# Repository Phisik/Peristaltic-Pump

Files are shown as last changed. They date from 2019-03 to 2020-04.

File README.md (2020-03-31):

# SUMMARY
There are several peristaltic pump projects on Thingiverse. However most of them lack source codes and could not be adjusted to use with different hose and bearings. I designed fully parametric peristaltic pump. It can be customized to use any silicon hose, any Nema motor, and any bearings. Source files are supplied. Feel free to modify it and adapt to suit your needs.

I have used silicon hose with OD=7 mm, ID=5.5 mm, and 0.75 mm wall. With that hose Nema 17HS4401S motor was able to pump 700 ml per minute (42 litres per hour) easily. Hoses with thicker walls may require to reduce motor speed or motor with higher torque.

# 3D PRINTING
The latest STL and SCAD source files of pump head are available at https://www.thingiverse.com/thing:3148717. I used 50% infill and 3 perimeters. The higher infill percentage the better. If rotor movement is too tight hose_clearance parameter can be increased. I use PET-G plastic for the case, and ABS for pump head to be able to pump hot liquids.

# HARDWARE
Additionally to pump head you will need to get some electronics:

    1. Nema stepper motor, e.g 17HS4401S. ~$8 
       https://www.aliexpress.com/item/32376023464.html
    2. Stepper motor driver, e.g A4988. ~$1  
       https://www.aliexpress.com/item/1817501276.html
    3. Arduino board. I used Arduino pro mini. ~ $2 
       https://www.aliexpress.com/item/32293707392.html
    4. Rotary encoder with button + 2 resistors or KY-040 Encoder Module. ~ $1 
       https://www.aliexpress.com/item/32474584136.html
    5. 1602 LCD with I2C converter. ~ $2 
       https://www.aliexpress.com/item/32836972320.html
    6. Bearings. I used 6 pcs of 605zz bearings. ~$10 for 50 pcs 
       https://www.aliexpress.com/item/32245721720.html
    7. Power supply 12V 1-2A. ~$4 
       https://www.aliexpress.com/item/1000001113368.html
    8. Rubber legs ~$1.5 for 20pcs 
       https://www.aliexpress.com/item/32844587782.html
    9. DC-DC converter ~$1.5 
       https://www.aliexpress.com/item/32261885063.html
    10. 2 springs ~$0.1  
        https://aliexpress.ru/item/2053018943.html
    11. Wires, screws, nuts etc.

I have ordered all parts from AliExpress. Links are provided as an example, you may not need 50pcs of bearings and can order only 10pcs. Total cost of the pump was about $35 including plastic for printing & other elecronic components.

# SOFTWARE
Source codes of Arduino firmware for DIY Nema motor based peristaltic pump are available in preset repository. 

Main features:

    1. Adjustable speed via RPM
    2. Adjustable speed via flow in ml per min
    3. Pumping predefined amount of liquid
    4. Pump calibration
    5. Soft start/stop
	6. Moisture sensor support to detect hose failure
	7. External control via analog/PWM signal
	8. Motor uptime & total pumped volume calculation 

Modes can be switched by single click. Double click is used for start/stop. Button hold enables pump calibration mode.

Video showing the pump in action: https://youtu.be/RnriTiulfPw

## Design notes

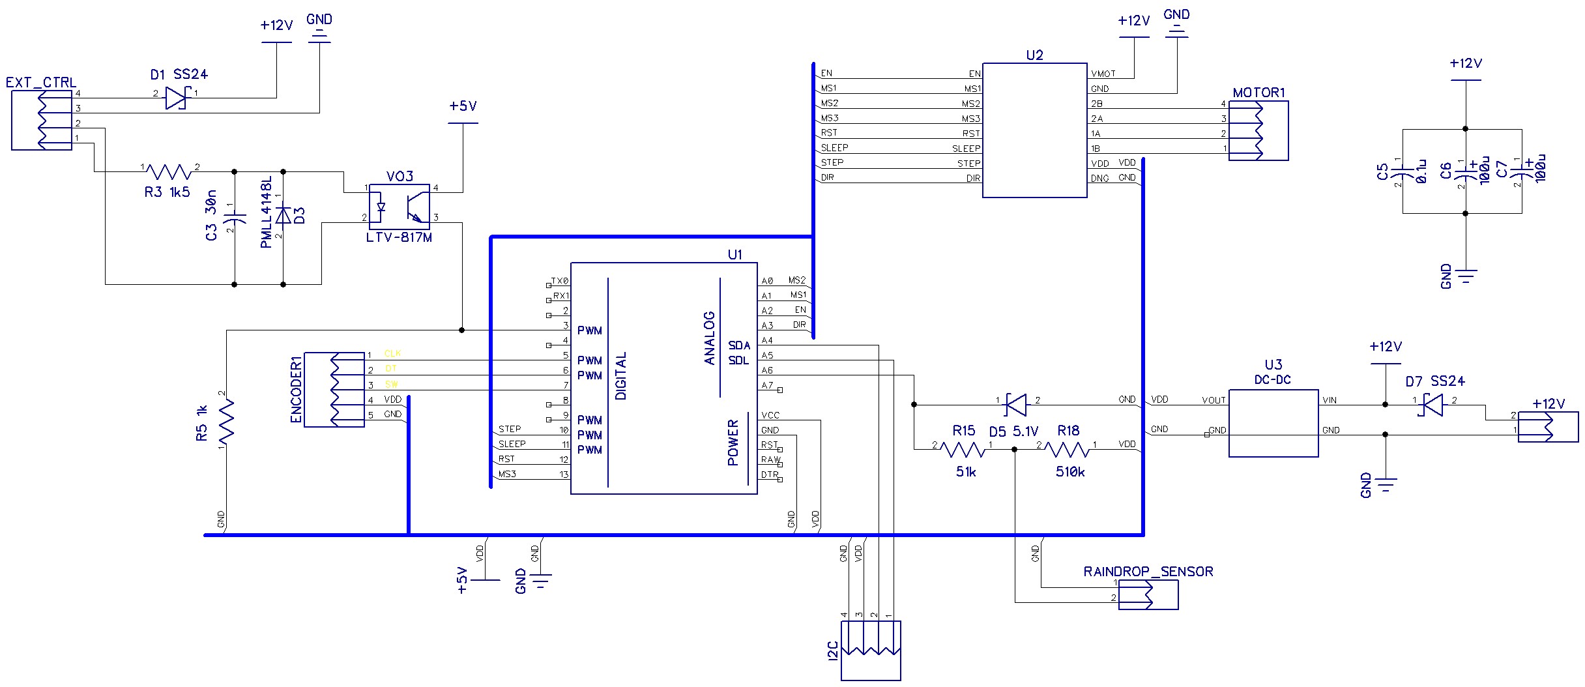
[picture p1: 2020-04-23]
docs/schematics.jpg

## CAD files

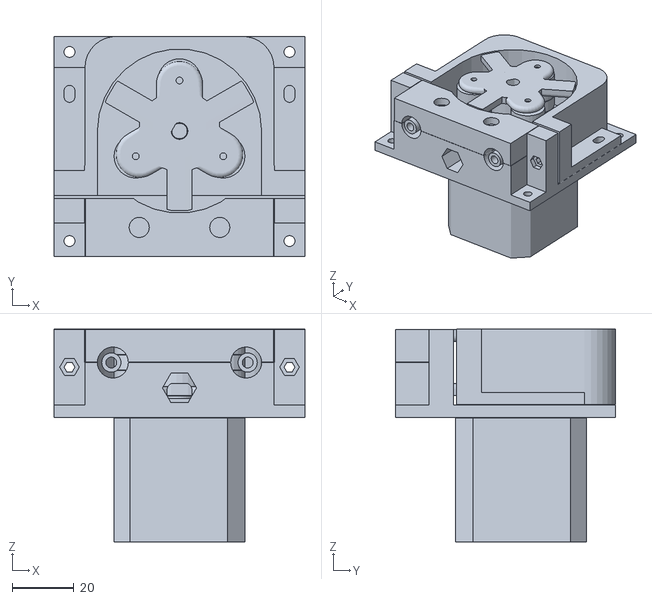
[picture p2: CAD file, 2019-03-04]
scad/head-assembly.stl
81.0 x 71.0 x 68.7

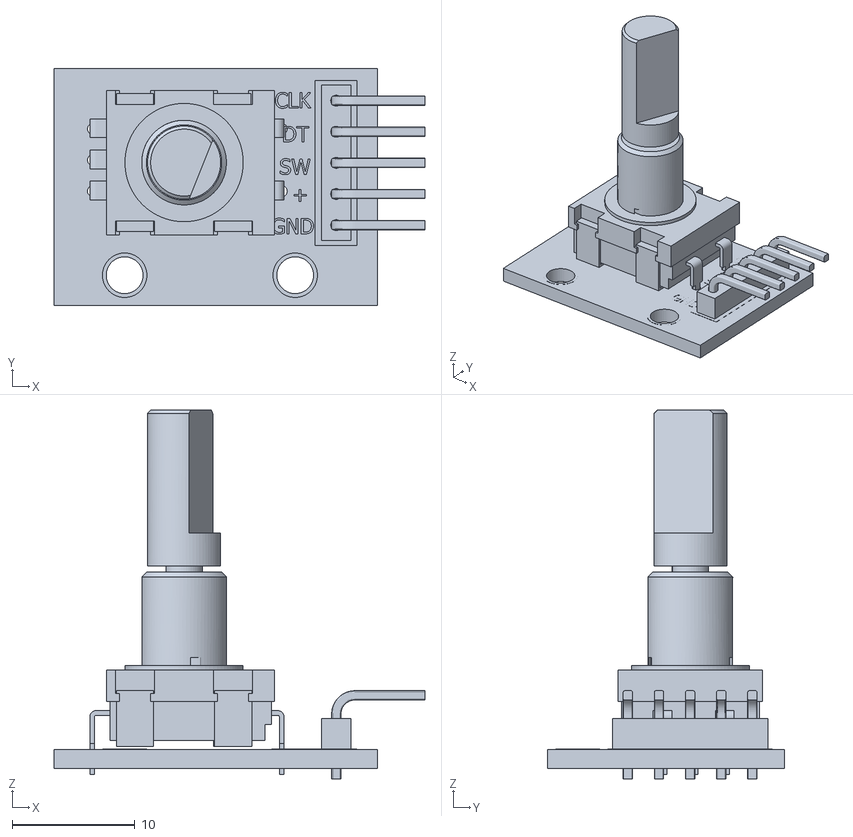
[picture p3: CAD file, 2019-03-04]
deps/ky-040.stl
30.3 x 19.3 x 30.1

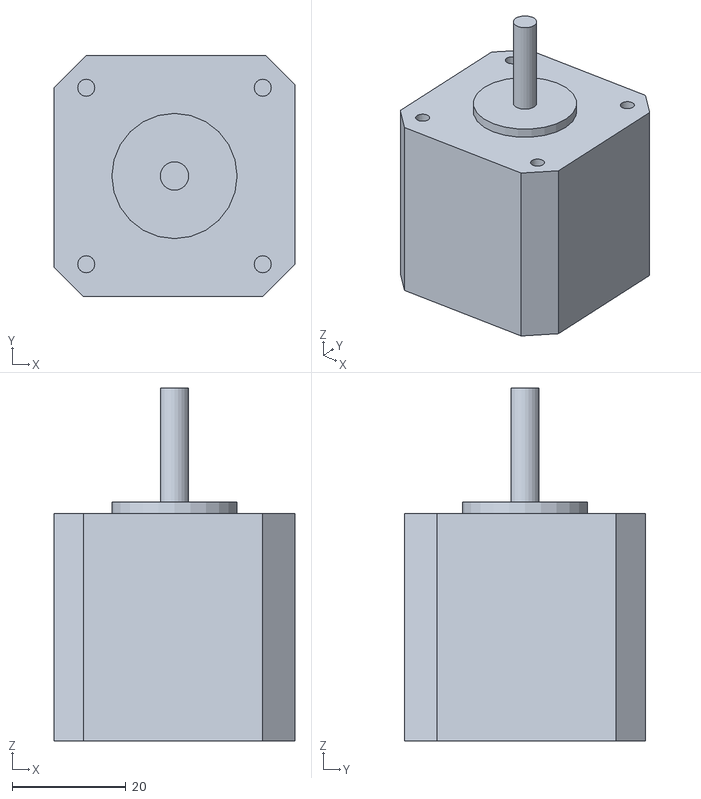
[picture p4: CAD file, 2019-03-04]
scad/deps/Nema17_40h.stl
42.3 x 42.3 x 62.0

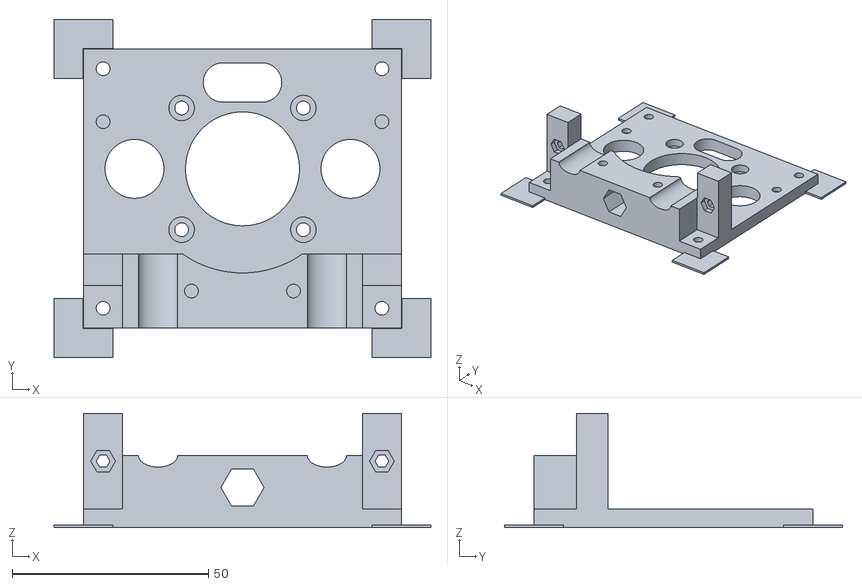
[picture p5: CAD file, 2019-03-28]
stl/pump-stator-base-with-support.stl
96.0 x 86.0 x 29.1

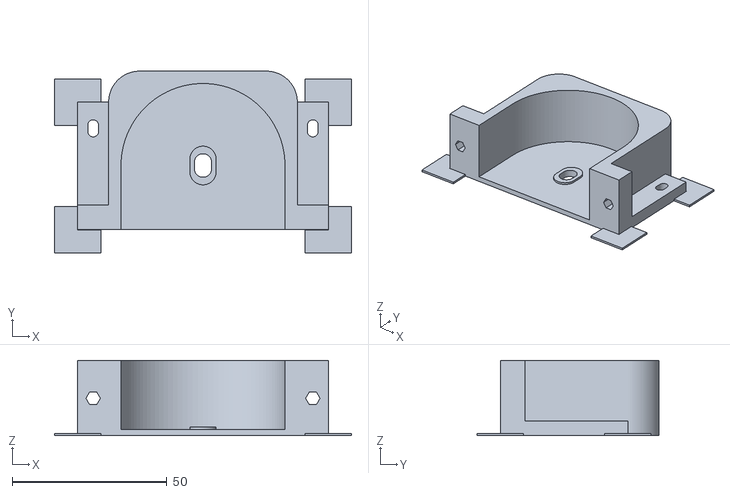
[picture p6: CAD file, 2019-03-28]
stl/pump-stator-support-with-support.stl
96.0 x 58.7 x 24.4

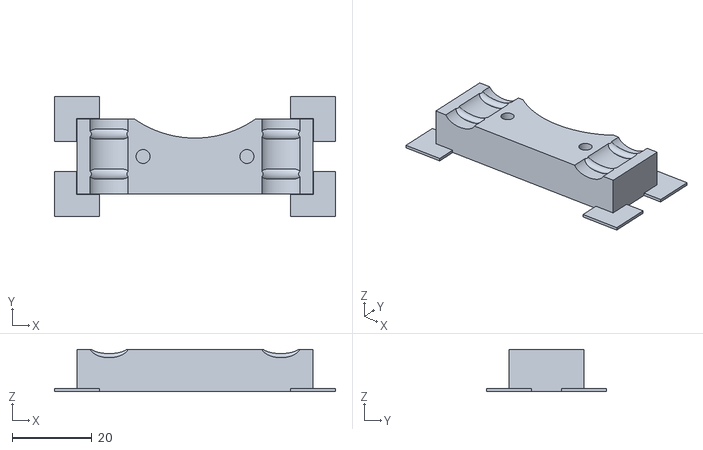
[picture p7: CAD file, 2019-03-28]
stl/pump-stator-cover-with-support.stl
70.3 x 30.0 x 10.6

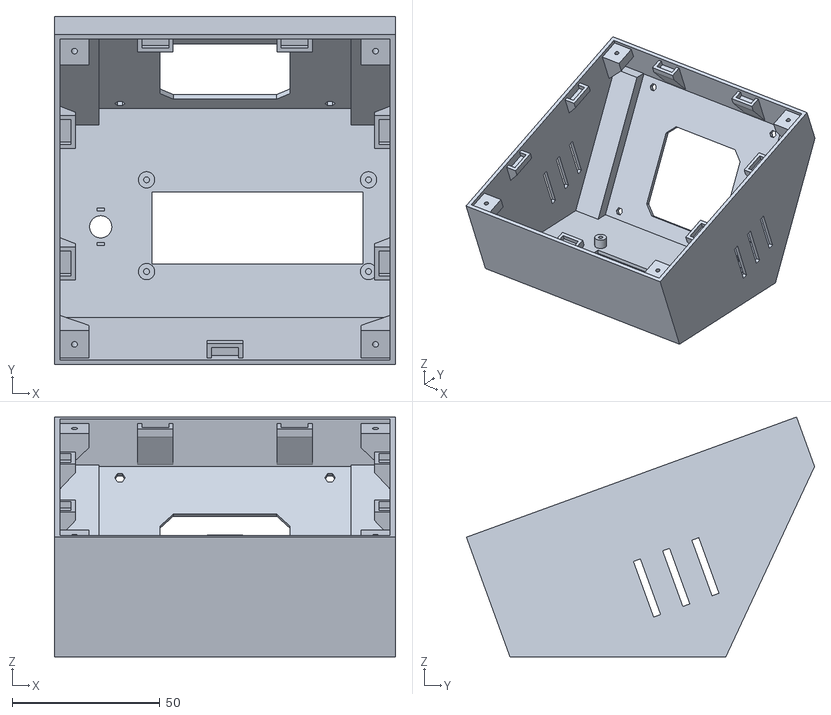
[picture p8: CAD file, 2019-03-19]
stl/case.stl
115.2 x 117.7 x 81.1

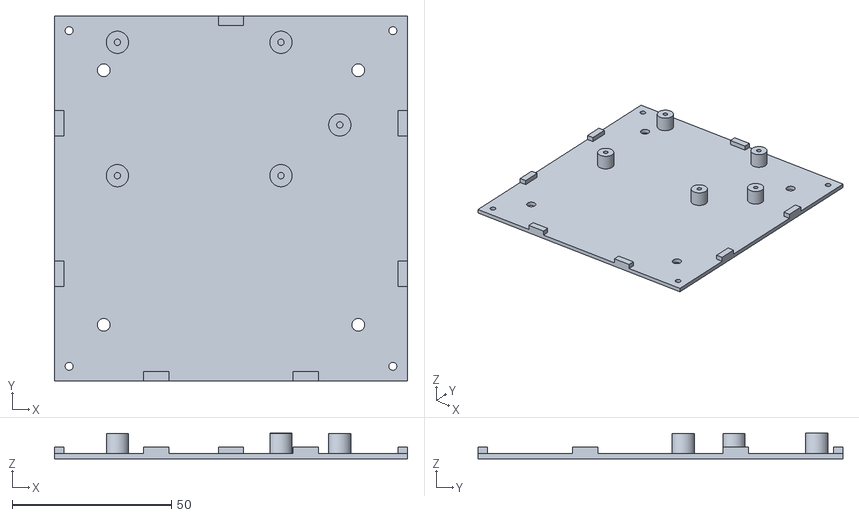
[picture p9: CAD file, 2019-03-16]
stl/case-bottom.stl
110.9 x 114.7 x 8.05

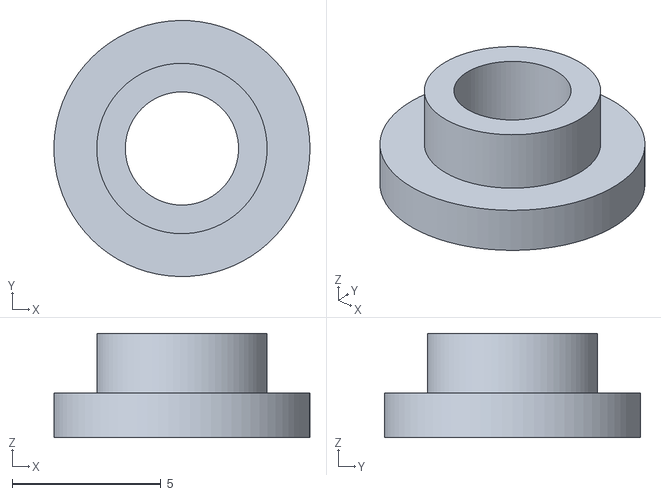
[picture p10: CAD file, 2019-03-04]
stl/spring-guide.stl
8.60 x 8.60 x 3.50

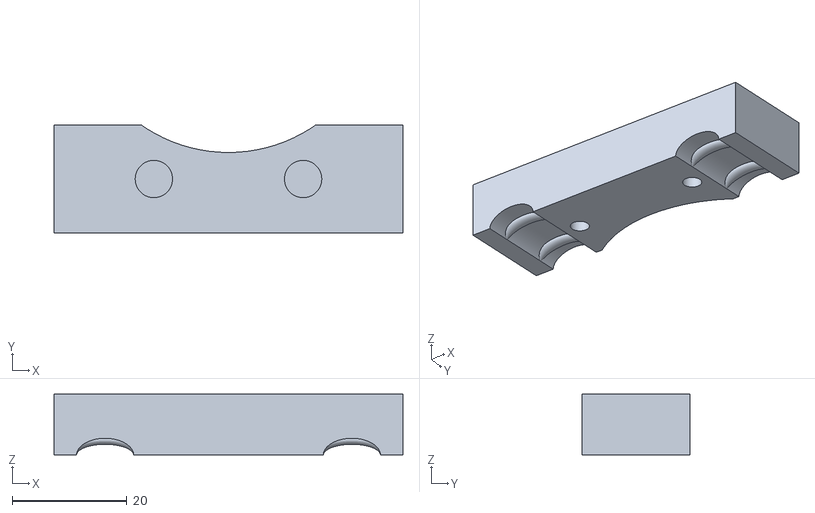
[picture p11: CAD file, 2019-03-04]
stl/pump-stator-cover.stl
60.8 x 18.8 x 10.6

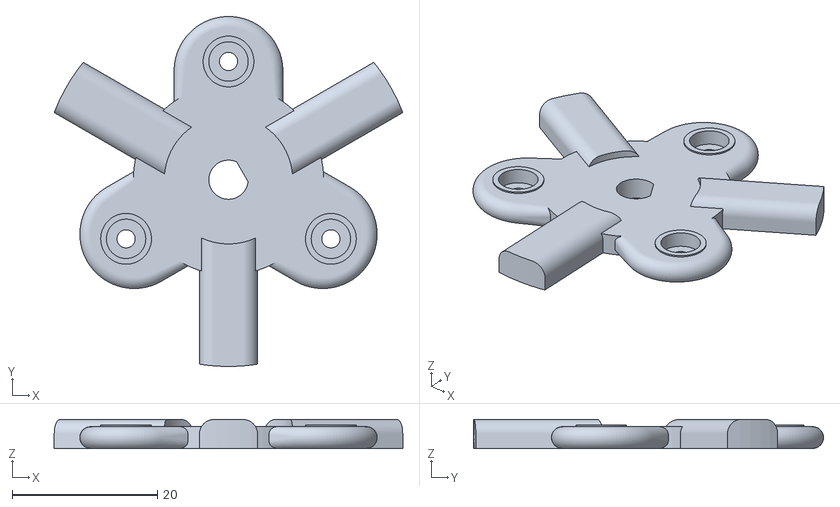
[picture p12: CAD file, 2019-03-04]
stl/pump-rotor-cover.stl
48.0 x 48.2 x 4.00

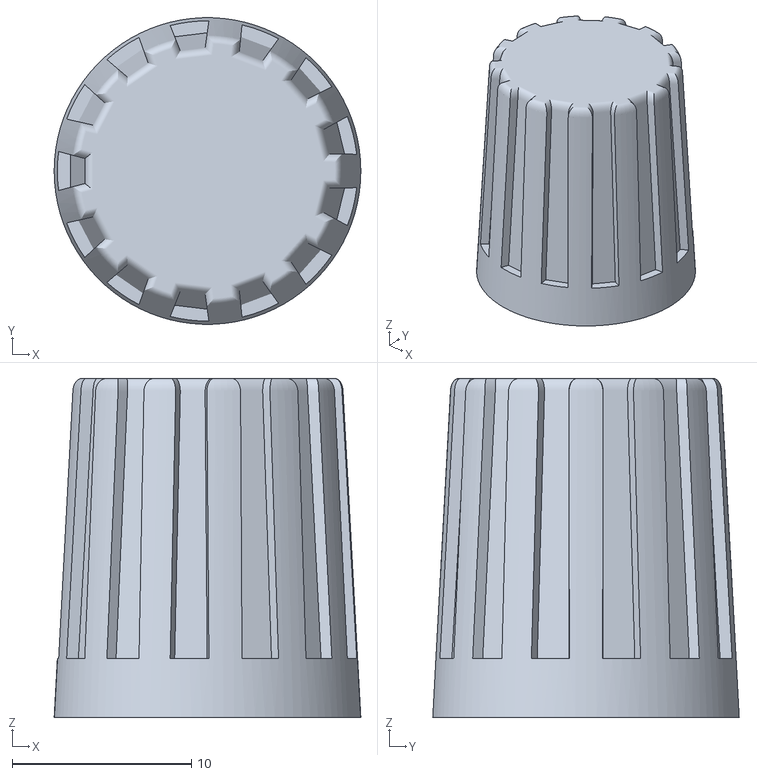
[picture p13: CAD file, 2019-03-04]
stl/encoder-knob.stl
17.1 x 17.1 x 18.9

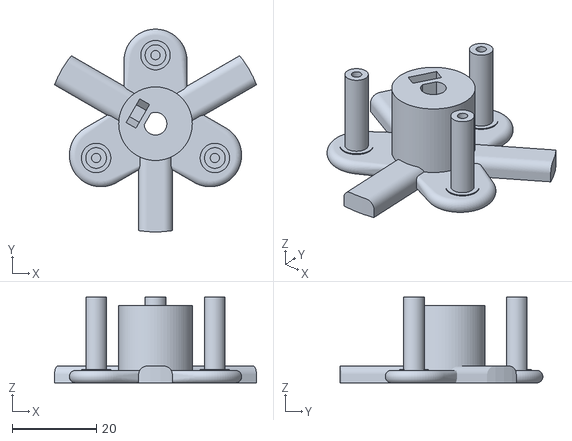
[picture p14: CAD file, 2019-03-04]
stl/pump-rotor-base.stl
48.0 x 48.2 x 20.4

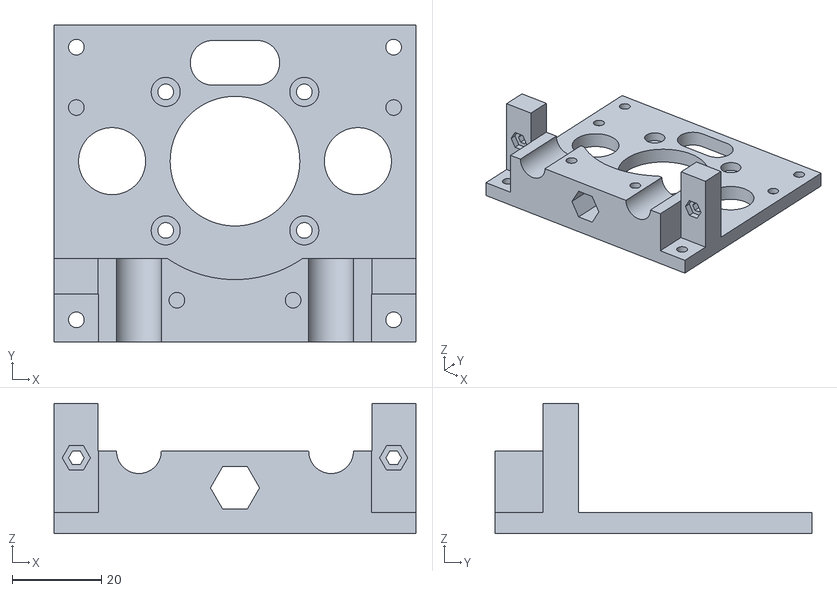
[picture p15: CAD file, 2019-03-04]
stl/pump-stator-base.stl
81.0 x 71.0 x 29.1

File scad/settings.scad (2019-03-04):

// Created by Phisik on 2018-12-16
// Main settings header for peristaltic pump

// Licence GPL

// some extra gap for clean difference render in preview
eps = 0.1;

// Part smoothness, the more the better
$fn = 100;

layer_height = 0.25;

// Silicon hose settings
//====================================================================================

// NB! The larger the hose radius the higher torque is required
r_hose = 22;        // radius of hose center line
                    // Update: after addition of groove hose center is at r_hose + hose_groove
d_hose = 9;         // hose external diameter

hose_wall = 1.5;   // hose wall thickness
					// NB! hose_wall affects both stator & rotor geometry
					
hose_clearance = 0.2;   // extra clearance between hose & bearings
						// NB! hose_clearance affects only rotor geometry
						// If you experience lack of suction reduce hose_clearance 
						// If motor misses steps increase hose_clearance, take motor with higher 
						// torque or hose with thinner wall

hose_fitting_delta_d = 1; // difference between hose and hose fitting diameter
						
						
// Stator settings
//====================================================================================
wall = 4;             // wall thickness, should be larger than hose_groove by 1mm or more
hose_groove = 0;     // NB! Rudiment form v1. Do not change. 
					 // groove depth for hose to stay in place 

h_base = 4.75;             // height of stator base
h_support_base = 2;		// height of support base

stator_support_gap = 1;		// gap between support & stator base for spring tension

stator_facet = 10;   // facets of outer support corners

mount_width  = 8;
mount_length = 10;

d_screw = 3.5;           // screw diameter
d_nut = 6.5;             // nut & screw head diameter
d_nut_tight = 5.5/0.87; // nut diameter for nuts to be fitted with soldering iron

l_handle = 10;

r_water_sink = 5.5;

need_nut_cuts_in_support = 0; // cut holes for nuts in support
need_nut_cuts_in_stator  = 1; // cut holes for support nut in stator

hose_fixator_length = 15;  // length of hose inset for fixing it on the stator


// Bearing settings
//====================================================================================
bearingNum = 3;     // Number of bearings per arm

h_bearing = 5;      // bearing height
d_bearing = 14;     // OD
d_bearing_axis = 5;         // ID
w_axis = 1;         // thickness of inner bushing



// Rotor settings
//==================================================================================== 
d_rotor = 17.5;   // Outer rotor diameter

arm_num = 3;    // number of rotor arms
w_arm  = 15;    // arm width
h_arm = 3;      // arm height

enable_hose_guides = 1;
w_hose_guide = 8;
hose_guide_clearance = 0.75;
r_hose_guide_facet = 2;

gap = 0.2;      // some clearance between joins & moving parts

arm_clearance = 4;  // clearance between arm and stator

bearing_axes_clearance = 0.075;  	     // clearance on rotor base between bearings and axes
rotor_bearing_axes_clearance = 0.45;  // clearance on rotor cap between axes and holes
bearing_clearance = 1; 				 // distance from stator base to the lowest arms

// 1602 lcd settings
//====================================================================================
y_lcd_hole = 31;
x_lcd_hole = 75;
d_lcd_hole = 3;

l_lcd_plate = 80;
w_lcd_plate = 36.11;
h_lcd_plate = 1.6;

l_lcd = 71.5;
w_lcd = 24.5;
h_lcd = 8.75;

x_lcd_shift = -0.1;
y_lcd_shift = +0.75;

l_lcd_i2c = 42;
w_lcd_i2c = 19;
h_lcd_i2c = 1.5;


// Nema 17 settings
//====================================================================================
nema_screw_distance = 31;  
nema_shaft_diameter = 5.5;
nema_shaft_height = 25;
nema_knob_diameter = 23;
nema_knob_height = 2.5;
nema_width = 42.3;
nema_angle_cut = 4;

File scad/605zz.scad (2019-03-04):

module 605zz() {
	difference(){
		cylinder(d=14, h=5);
		cylinder(d=11, h=5);
	}
	difference(){
		cylinder(d=7, h=5);
		cylinder(d=5, h=5);
	}

	translate([0,0,0.25])
	difference(){
		cylinder(d=11, h=4.5);
		cylinder(d=7, h=4.5);
	}
}

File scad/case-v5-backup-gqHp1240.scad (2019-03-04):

// Created by Phisik on 2018-10-20
// Case for open source peristaltic pump

// Licence GPL 
// You are free to distibute & contribute to this part in any form

// Settings
//==============================================================================
include <settings.v3>
use <lcd1602.scad>

assembly      = 0;   // render assembly
render_top    = 1;   // render top part
render_bottom = 0;   // render bottom part
render_side_panel = 1;   // render bottom part

enable_angle_support = 1;

h_layer_height = 0.25;
w_angle_support = 15;
n_support_layers = 3;
angle_support_clearance = 0.15;


rubber_legs = true;
d1_rubber_legs = 15;
d2_rubber_legs = 18;
h_rubber_legs  = 5;

h_case = 68;
w_case = 115;
l_case = 117;

nema_clearance = 0.8;

// Front panel settings
front_angle=20;
back_angle=45;
wall_case = 0.46*cos(front_angle)*4;
wall_size_scale = 1/cos(front_angle);  // when 3d printing tilded walls will be thicker




w_front_panel = w_lcd_plate + 36.8;

d_lcd_stand = d_lcd_hole+2.5;
d_lcd_stand_hole = 2;

r_ext = r_hose + d_hose/2 + wall - hose_groove;
handle_length = r_ext+l_handle;
w_back_panel = handle_length+r_ext;


extra_lcd_n_ecn_shift = 5;

lcd_clearance = -0.1;
x_1602_shift = 11;
y_1602_shift = -y_lcd_shift+extra_lcd_n_ecn_shift;
z_1602_shift = -6;

x_enc_shift = -40;
y_enc_shift = 2.2+extra_lcd_n_ecn_shift;
z_enc_shift = -8.5;


// PCB settings
l_pcb = 58.4;
h_pcb = 1.6;
w_pcb = 49;
x_pcb_hole = 51.4;
y_pcb_hole = 41.91;
d_pcb_hole = 2;
x_shift_pcb = 0;
y_shift_pcb = -29.5;
z_shift_pcb = 8;
d_pcb_leg = 7;
d_pcb_leg_hole = 2;

alpha = 1;

// ventillation holes settings
n_vent = 3;
h_vent = 20;
w_vent = 2.5;
dist_vent = 8;
vent_y_shift = 45;
vent_z_shift = 27;

// bottom plate settings
d_bottom_legs_holes = 4;
d_bottom_holes = 2.5;
d_bottom_legs = 20;
h_bottom_legs = 4;
legs_shift = w_case/2-d_bottom_legs/2-7.5;
cover_clearance = 0.3;

// some extra clips to hold side walls
clip_shift = 30;
l_clip = 8;
w_clip = 3;
h_clip = 2;
clip_wall = 2;
clip_clearance = 0.5;

// bottom plate holders
holders_size = 10;
d_holder_hole = 2;

// Assemble all parts
//==============================================================================
if(assembly) {
    alpha = 1;
    

    color("red", alpha) 
        translate([x_shift_pcb, y_shift_pcb, z_shift_pcb]) 
        pcb();
    
    color("green", alpha) 
        translate([0,-l_case, h_case-w_back_panel*sin(back_angle)]) 
        rotate([back_angle, 0, 0])  
        translate([0,handle_length, 0]) 
        import("pump-v3-assembly.stl");
    
    if(render_top)       case_main();
    if(render_bottom)    { 
        bottom_cover(); 
        if(rubber_legs) color("gray") draw_rubber_legs(); 
    }
} else {
    if(render_top) {
        translate([0, -w_front_panel/2, 0])
        rotate([180+front_angle, 0, 0]) 
            translate([0, -wall_case, -h_case+w_front_panel*sin(front_angle)])
            case_main();
        
        difference(){
            union() {
                for(sx=[1, -1]) for(sy=[1, -1])
                    translate([sx*(l_case-wall_case)/2, sy*w_front_panel/2, n_support_layers*h_layer_height/2])
                    cube([w_angle_support, w_angle_support, h_layer_height*n_support_layers], center=true);

            }
            
            translate([0,0,h_layer_height/2]) hull(){
                h = 50; d=angle_support_clearance;
                cube([l_case-wall_case+d/2, w_front_panel+d, h_layer_height], center=true);
                translate([0,-h*sin(front_angle)+h*sin(back_angle-front_angle),h-h_layer_height])
                    cube([l_case-wall_case+d/2, w_front_panel+d+h*sin(front_angle)+h*sin(back_angle-front_angle), h_layer_height], center=true);
            }
        }
        
        // enable_angle_support = 1;
        //h_angle_support = 0.5;
        // w_angle_support = 10;
    }
    if(render_bottom)    bottom_cover();
}
// Assemble


// Bottom cover
//==============================================================================
module bottom_cover() {
    difference() {
        translate([-w_case/2 + wall_case + cover_clearance,
                   -l_case + wall_case + cover_clearance, 0]) 
           cube([
                w_case-2*wall_case-2*cover_clearance, 
                l_case-wall_case-2*cover_clearance, 
                wall_case], center=false);
    
        if(rubber_legs) {
            translate([0,-l_case/2 + 0.5*wall_case + cover_clearance, -eps]) {
                translate(legs_shift*[1,1,0])    
                    cylinder(d=d_bottom_legs_holes, h=h_bottom_legs);
                translate(legs_shift*[1,-1,0])    
                    cylinder(d=d_bottom_legs_holes, h=h_bottom_legs);
                translate(legs_shift*[-1,1,0])    
                    cylinder(d=d_bottom_legs_holes, h=h_bottom_legs);
                translate(legs_shift*[-1,-1,0])    
                    cylinder(d=d_bottom_legs_holes, h=h_bottom_legs);
           }
        } else {  
            translate([x_shift_pcb, y_shift_pcb, 0]){
              translate([x_pcb_hole, y_pcb_hole, -eps]/2)
                    cylinder(d=d_bottom_holes, h=wall_case+1);
                translate([x_pcb_hole, -y_pcb_hole, -eps]/2)
                    cylinder(d=d_bottom_holes, h=wall_case+1);
                translate([-x_pcb_hole, y_pcb_hole, -eps]/2)
                    cylinder(d=d_bottom_holes, h=wall_case+1);
                translate([-x_pcb_hole, -y_pcb_hole, -eps]/2)
                    cylinder(d=d_bottom_holes, h=wall_case+1);
            } // pcb holes
        }
        
                 
        // holders for bottom plate
        translate([-w_case/2+wall_case-eps, eps, -eps]) 
            holder_hole(holders_size, d_bottom_holes);
        translate([-w_case/2+wall_case-eps, -l_case+wall_case+holders_size-eps, -eps]) 
            holder_hole(holders_size, d_bottom_holes);
        translate([w_case/2-wall_case+eps, -l_case+wall_case-eps, -eps]) 
            rotate([0,0,180]) 
            holder_hole(holders_size, d_bottom_holes);
        translate([w_case/2-wall_case+eps, -holders_size+eps, -eps]) 
            rotate([0,0,180]) 
            holder_hole(holders_size, d_bottom_holes);
    }

    
   
   if(rubber_legs) {  
        // pcb holder
        translate([x_shift_pcb, y_shift_pcb, 0]){
            translate([x_pcb_hole, y_pcb_hole, +eps]/2) pbc_leg();
            translate([x_pcb_hole, -y_pcb_hole, 0]/2)   pbc_leg();
            translate([-x_pcb_hole, y_pcb_hole, 0]/2)   pbc_leg();
            translate([-x_pcb_hole, -y_pcb_hole, 0]/2)  pbc_leg();
        } // pcb holder
        
    } else {
        translate([0,-l_case/2 + 0.5*wall_case + cover_clearance, -h_bottom_legs]) {
            translate(legs_shift*[1,1,0])    
            cylinder(d=d_bottom_legs, h=h_bottom_legs);
                translate(legs_shift*[1,-1,0])    
            cylinder(d=d_bottom_legs, h=h_bottom_legs);
                translate(legs_shift*[-1,1,0])    
            cylinder(d=d_bottom_legs, h=h_bottom_legs);
                translate(legs_shift*[-1,-1,0])    
            cylinder(d=d_bottom_legs, h=h_bottom_legs);
       }
    }

    module pbc_leg() {
        difference() {
            cylinder(d=d_pcb_leg, h=z_shift_pcb);
            cylinder(d=d_pcb_leg_hole, h=z_shift_pcb);
        }
    }
    module holder_hole(size, d){
        translate([size/2, -size/2, 0])
                cylinder(d=d,h=20);
    }
    
    // clips
    // we can print either clips or plastic legs
    if(rubber_legs){
        translate([-w_case/2 + cover_clearance +wall_case, 0, wall_case]) {
            translate([0, -clip_shift-l_clip, 0])
                cube([w_clip, l_clip, h_clip]);
            translate([0, -l_case+wall_case+clip_shift, 0])
                cube([w_clip, l_clip, h_clip]);
        }
         
        translate([+w_case/2 - cover_clearance - wall_case - w_clip, 0, wall_case]) {
            translate([0, -clip_shift-l_clip, 0])
                cube([w_clip, l_clip, h_clip]);
            translate([0, -l_case+wall_case+clip_shift, 0])
                cube([w_clip, l_clip, h_clip]);
        }
        
        translate([0, -l_case+wall_case+cover_clearance, wall_case]) {
            translate([w_case/2 -clip_shift  - l_clip, 0, 0])
                cube([l_clip, w_clip, h_clip]);
            translate([-w_case/2 + clip_shift, 0, 0])
                cube([l_clip, w_clip, h_clip]);
        }
        
        translate([- l_clip/2, -w_clip-cover_clearance, wall_case])
            cube([l_clip, w_clip, h_clip]);
    }
}
// module bottom_cover()
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

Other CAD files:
stl/case-with-support.stl
stl/pump-stator-support.stl
scad/case.scad
scad/hose_fixator.scad
scad/hose_joiner.scad
scad/lcd1602.scad
scad/pump-v5.scad
scad/pump.scad
scad/spring_holder.scad
stl/hose-joiner.stl

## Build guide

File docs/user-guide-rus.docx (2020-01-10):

ИНСТРУКЦИЯ

к перистальтическому насосу для НБК

(прошивка v3.8 и выше)

Екатеринбург 2019

# ТЕХНИЧЕСКИЕ ХАРАКТЕРИСТИКИ

Название | Значение
Напряжение питания | 9–19 Вольт
Максимальная потребляемая мощность | 10 Вт
Максимальный потребляемый ток | 1.8 А
Параметры шланга (OD*ID*толщина стенки) | 9*6*1.5 мм
Примерный ресурс силиконового шланга | 2–3 м³
Скорость подачи жидкости | 0.1–65 л/час
Скорость вращения ротора | 0–450 об/мин
Шаг регулировки скорости подачи | 1 об/мин (0.1 л/час)
Режим регулировки об/мин | Есть
Режим регулировки л/ч | Есть
Режим розлива (бутилирование) | Есть
Плавные разгон/остановка | Есть
Сохранение данных во внутреннюю память | Есть
Калибровка насоса | Есть
Быстрый старт/стоп | Есть
Контроль разрыва шланг | Опционально
Внешнее управление | Опционально

# МЕРЫ ПРЕДОСТОРОЖНОСТИ

1. Не рекомендуется оставлять работающий насос без присмотра. В случае повреждения шланга возможен разлив жидкости. Также возможно заклинивание ротора, что приведет к нарушению процесса перегонки.

2. Неправильная полярность питания приведет к повреждению электроники! На внутренний пин коннектора должно подаваться положительное напряжение питания. Ниже приведено обозначение «правильного» блока питания:

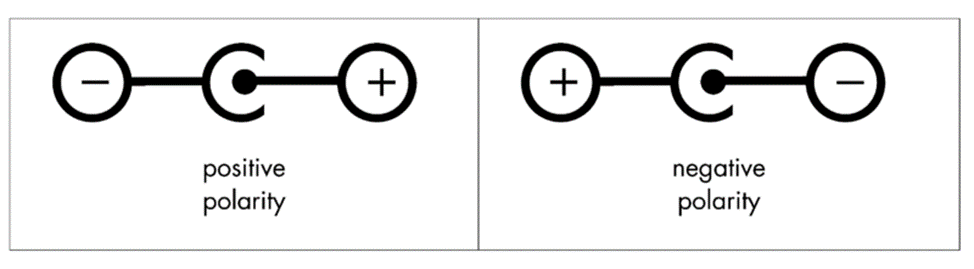
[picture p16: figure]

3. Для питания насоса можно использовать блок питания с напряжением 9–19В и током 1.5–2А, например такой, как на рисунке ниже:

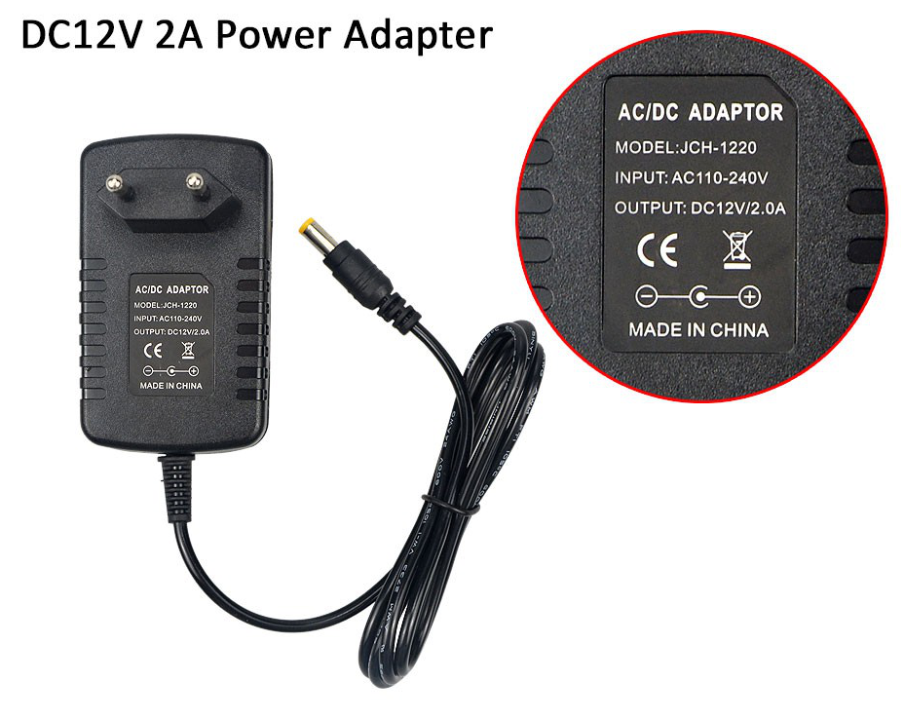
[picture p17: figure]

4. Необходимо беречь насос от попадания внутрь влаги. Не использовать насос мокрыми руками. Корпус насоса негерметичен. Попадание внутрь воды приведет к повреждению электроники.

5. Корпус насоса выполнен из PLA пластика, который размягчается при температуре 50С. Поэтому насос нельзя ставить на махровое полотенце или накрывать чем либо, это приведет к деформации корпуса. Нельзя оставлять насос у отопительных приборов, и около любых горячих поверхностей. Нельзя сушить насос феном. Следует проявлять осторожность при перекачивании горячих жидкостей, головка выполнена из термостойкого ABS пластика, однако необходимо следить, чтобы корпус насоса не нагревался от головки.

6. Запрещается обесточивать насос до его полной остановки. Это может привести к выходу из строя блока управления двигателем.

# ОБЩИЙ ВИД ИЗДЕЛИЯ

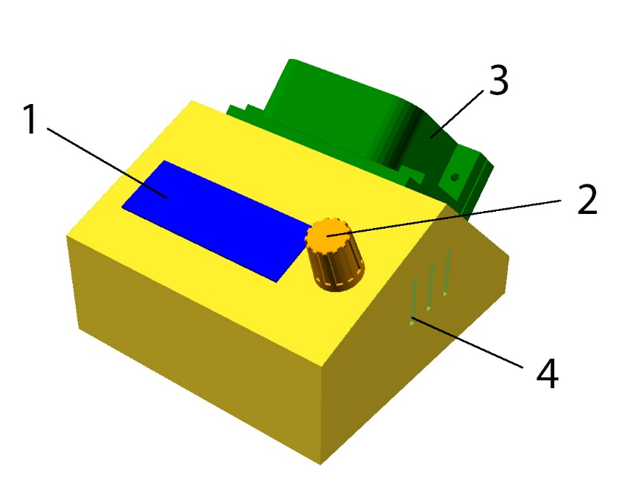
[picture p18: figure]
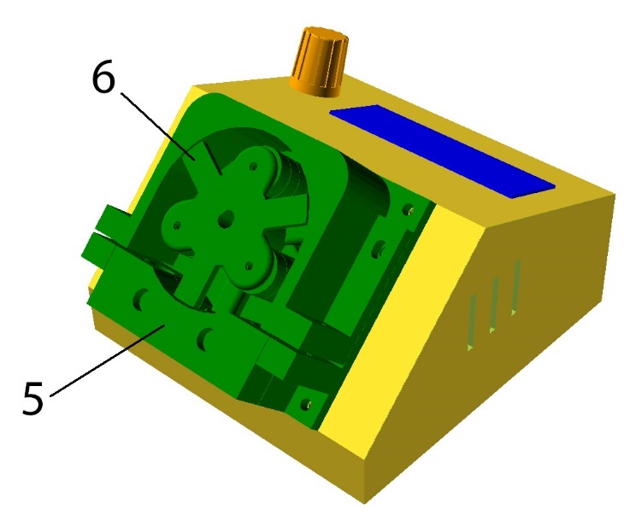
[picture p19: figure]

Рис.1 Элементы управления и конструкции насоса

1. Жидкокристаллический экран.
2. Ручка управления насосом со встроенной кнопкой (энкодер).
3. Перистальтическая головка.
4. Отверстия для вентиляции.
5. Съемная крышка, фиксирующая шланг.
1. НАЧАЛО РАБОТЫ. ОТОБРАЖЕНИЕ ИНФОРМАЦИИ ПРИ ВКЛЮЧЕНИИ НАСОСА.

Насос включается при подключении блока питания. Дополнительный выключателей не предусмотрено. После включения на экране последовательно высвечивается:

1. Версия прошивки платы управления.
2. Общее время работы двигателя насоса.
3. Объем жидкости, перекачанный с текущим шлангом.
4. Объем жидкости, перекачанный насосом за все время.
5. Предупреждение о замене шланга (показывается только в том случае, если подошло время замены шланга).

Если во время включения насоса удерживать нажатой кнопку энкодера, то будет вызвано меню обнуления объема жидкости, перекачанной с текущим шлангом.

# УПРАВЛЕНИЕ НАСОСОМ

Управление насосом полностью осуществляется ручкой энкодера. Ручка имеет встроенную кнопку, которая срабатывает при нажатии. Возможные действия приведены в таблице

Действие | Результат
Вращение ручки | 1. Регулировка скорости вращения/подачи 2. Регулировка объема при розливе 3. Выбор пунктов в меню
Одиночное нажатие кнопки | 1. Переключение режимов работы 2. Подтверждение выбора в меню («Enter»)
Двойное нажатие кнопки | 1. Быстрый старт/стоп в непрерывных режимах работы 2. Старт насоса в режиме розлива 3. Запуск в режиме внешнего управления
Удержание нажатой кнопки | 1. Переход в режим калибровки 2. Меню настройки режима бутилирования 3. Меню настройки внешнего управления

# ОПИСАНИЕ РЕЖИМОВ РАБОТЫ

1. Режим регулировки скорости вращения. В этом режиме пользователь может точно установить скорость вращения головки насоса в диапазоне от 0 до 450 об/минуту с шагом в 1 об/мин. Насос будет находиться в этом режиме до тех пор, пока пользователь вручную не остановит его. Двойным нажатием кнопки энкодера можно быстро остановить насос и в дальнейшем возобновить его работу на той же скорости.
2. Режим регулировки скорости подачи. В этом режиме пользователь может точно установить скорость расхода жидкости в диапазоне от до 65 л/час с шагом 0.1 л/час. Насос будет находиться в этом режиме до тех пор, пока пользователь вручную не остановит его. Двойным нажатием кнопки энкодера можно быстро остановить насос и в дальнейшем возобновить его работу на той же скорости. Внимание! Показания на экране насоса будут соответствовать реальной скорости подачи только после проведения процедуры калибровки насоса.
3. Режим розлива/бутилирование. В этом режиме пользователь задает объем жидкости, который нужно перекачать. После двойного нажатия на кнопку энкодера, насос запускается и начитает отсчет. На экране при этом отображается доля уже перекачанной жидкости. Двойным нажатием кнопки энкодера можно остановить процесс перекачивания и возобновить его в дальнейшем. Внимание! Объем перекачанной жидкости будет соответствовать реальности только после процедуры калибровки насоса. Удержание нажатой кнопки энкодера вызывает меню, в котором можно изменить скорость перекачивания и шаг изменения объема.
4. Внешнее управление. В этом режиме насос управляется внешним сигналом, например от контроллера самогонного аппарата. Необходимо вручную подтвердить запуск насоса двойным нажатием на кнопку энкодера. Также двойным нажатием можно приостановить внешнее управление. Когда насос остановлен на экране высветится надпись «Stopped». Числовые показания на экране отражают текущую скорость в процентах от максимальной (~200 об/мин). Удержание нажатой кнопки энкодера вызывает меню, в котором можно изменить направление вращения головки и калибровочный множитель f, используемый для масштабирования входного сигнала. Дополнительную информацию о цоколёвке разъема внешнего управления, калибровочном множителе и форме управляющего сигнала см в разделах 9 и 10.

# КАЛИБРОВКА НАСОСА

Калибровка насоса необходима для пересчета числа оборотов головки насоса в объем перекачанной жидкости. Без процедуры калибровки показания насоса в режимах 2 и 3 (см. «Описание режимов работы») не будут соответствовать реальности.

Переход в режим калибровки осуществляется длительным нажатием на кнопку энкодера. В любой момент можно отменить калибровку также длительным нажатием. Калибровка состоит в том, чтобы измерить объем жидкости, который насос перекачает для калибровки (около 0.5–0.55 л), и сохранить эти данные в памяти насоса. Процедура калибровки выполняется в следующем порядке:

1. Опустить оба шланга в одну емкость с жидкостью и запустить насос в одном из непрерывных режимом (1 или 2) до полного наполнения шлангов.
2. Длительным нажатием кнопки перейти в режим калибровки.
3. Одиночным нажатием подтвердить начало процесса калибровки.
4. Выбрать направление вращения головки, в котором будет производиться калибровка (по часовой/против часовой/оба), и подтвердить выбор одиночным нажатием.
5. Опустить соответствующие шланги в питающую и приемную емкости и подтвердить готовность одиночным нажатием. Насос начнет перекачивать жидкость.
6. Измерить количество перекачанной жидкости и ввести соответствующие показания с помощью вращения ручки энкодера
7. Сохранить показания в память насоса одиночным нажатием.
8. Повторить пп. 5–7 для калибровки в противоположном направлении.

# ЗАМЕНА ШЛАНГА

При работе насоса шланг изнашивается. Ресурс стандартного силиконового шланга составляет 2.5–3.5 м³. Производите своевременную замену шланга, не допускайте работы насоса со шлангом, имеющим протечки.

Замена шланга выполняется в следующем порядке:

1. Остановить насос, отключить блок питания от сети 220В.
2. Открутить 2 винта крышки 5 (см. рис 1), убрать крышку и, вращая ротор, освободить изношенный шланг.
3. Отрезать около 25 см нового шланга. Подойдет шланг с внутренним диаметром ≤ 6мм и толщиной стенки строго 1.5мм.
4. Вращая ротор, заправить и выровнять новый шланг по длине и высоте.
5. Зафиксировать шланг, поставив на место крышку 5 и закрепив ее винтами.
6. Смазать «усы» ротора 6 (рис. 1) и поверхность нового шланга небольшим количеством силиконового масла.

# ИСПОЛЬЗОВАНИЕ ДАТЧИКА РАЗРЫВА ШЛАНГА

Если ваш насос оборудован датчиком влажности, то его можно использовать для контроля повреждения шланга. Для этого необходимо подключить датчик влажности в соответствующий разъем и положить его под насос в районе отверстия для слива воды. При повреждении шланга, вода, выходя из отверстия для слива, попадет на датчик, датчик сработает, и насос остановит подачу. На экране при этом высветится сообщение о повреждении шланга. Если срабатывание защиты произошло в результате случайного попадания жидкости на датчик влажности, то необходимо протереть датчик насухо и одиночным нажатием на кнопку энкодера продолжить работу.

# ПОДКЛЮЧЕНИЕ К ВНЕШНЕМУ КОНТРОЛЛЕРУ

Внешнее управление насосом осуществляется ШИМ сигналом. Значение скорости вращения головки насоса ω при этом определяется коэффициентом заполнения входного сигнала D по следующей формуле:

ω=f⋅D⋅ω_(max) ,

где ω_(max) — это максимальная скорость вращения головки насоса (450 об/мин), f — калибровочный множитель. Допустимые параметры входного сигнала приведены в таблице:

Амплитуда, В | 3.3–5
Частота, Гц | 0–1000
Коэффициент заполнения | 0–1

# ЦОКОЛЕВКА ВНЕШНИХ РАЗЪЕМОВ

Насос в зависимости от исполнения может иметь 2 внешних разъема. Разъем датчика разлития шланга имеет 2 контакта, разъем внешнего управления — 3. На рис. 2 приведена схема подключения контактов к цепям платы управления. Будьте предельно внимательны при подключении питания через разъем внешнего управления, ошибка в полярности подключения контактов питания приведет к повреждению платы управления насосом.

Необходимо следить, чтобы на датчик влажности не попадало никакое напряжение питания, так как он подключен напрямую к плате управления насосом. При попадании на датчик влажности напряжения выше 5В плата управления насосом может быть повреждена.

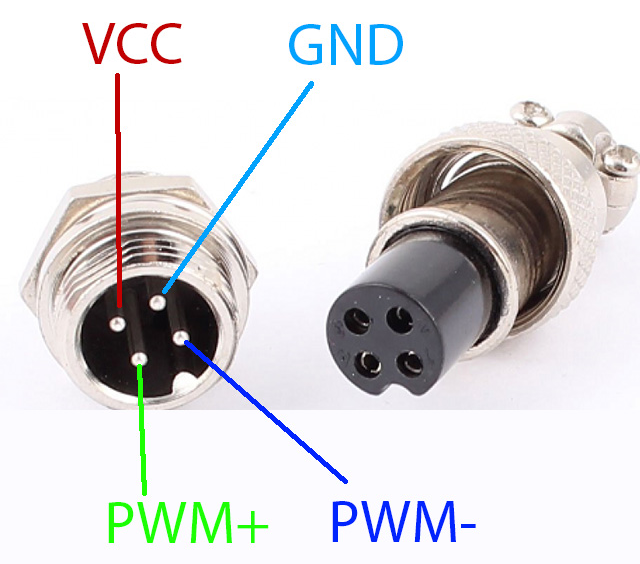
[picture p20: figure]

Рис.2 Цоколевка разъема внешнего управления
1: сигнал+, 2: питание +, 3: питание-, 4: сигнал -

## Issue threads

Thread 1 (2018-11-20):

No matching function for call to 'LiquidCrystal_i2C::begin()'

arguy58, 2018-11-20:
The code will not verify in Arduino 1.8.7  Also INO.File  cannot be named "Peristaltic pump.ino".. No spaces aloud..  Sorry, I don't like to point at issues.

Phisik, 2018-11-27:
Thanks! I have updated code and added external dependencies that works for me. Also added case files, check it out.

Closed 2018-11-27.

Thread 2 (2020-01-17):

47u slots

gcarrascohuertas, 2020-01-17:
Thanks you for your project. It's awesome!

I have a question refered to 47u slots in PCB scheme. These two slots are for 47 microFarads capacitors?
Thanks you in advance

gcarrascohuertas, 2020-01-17:
Also if 47 microFarads capacitor is needed. Which voltage is required ? 47 microFarads -  16V ?

Phisik, 2020-04-23:
Hello! Yes, you are right. It's better to solder a couple of 47-100u caps on the board. However it mostly will do ok wihout them. I would suggest to use the capacitors with max voltage 2 time higher than VIN, e.g. if VIN=12V then take 25V caps.

Closed 2020-04-23.

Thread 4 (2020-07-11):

Lcd is showing nothing

SaiPreetham8, 2020-07-11:
Hello,
I have done the same project by using aurdino uno, and uploaded the program. But the lcd is showing blank and nothing is coming out of it. Can you help me!

dohany, 2020-07-11:
Hello,

I am new to arduino and I would like to try this project too. I got all the parts but then I confused how to connect them. Should I solder all the connections? And also how do you managed to power supply? I got the adapter and then I realised there is no jack plug to connect the adapter. Also I cant figure it out how to upload code to arduino mini pro because there is no usb connection on it. I appreciate if you can answer.

SaiPreetham8, 2020-07-11:
For aurduino mini you have to get usb board 5 pin or 6 pin to upload your program. For Power supply I am using aurdino uno so iam confused how the connections go

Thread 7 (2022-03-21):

Hose 4mm ID / 6mm OD

guestisp, 2022-03-21:
Hi.
Could you please share some settings for a silicone hose having 4mm ID and 6mm OD ?

I've set `d_hose = 6` and `hose_wall = 1` but OpenSCAD is writing: `Warning: hose OD is too big, hose guides will touch & wear the hose`

What's the meaning of `r_hose` and which value should I set ?

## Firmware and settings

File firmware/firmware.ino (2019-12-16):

#include <Wire.h>
#include <LiquidCrystal_I2C.h>
#include <ClickEncoder.h>
#include <EEPROM.h>

const double firmwareVersion = 2.4;

// Firmware features
//==============================================================================================

// Enable debug output to Serial
#define DEBUG_ENABLED 0

// EEPROM magic byte, increment this to clear EEPROM settings
#define MAGIC_BYTE 19041301L

// Show litres per hour instead of millilitres per minute
#define DISPLAY_LITRES_PER_HOUR 1

// Pump stops when enters MODE_BOTTLING, if you do not this mode it you can switch it off
#define ENABLE_MODE_BOTTLING 1

// Starting from v2.0 pump saves total motor uptime & pumped volume to eeprom, disable it if not used
#define ENABLE_UPTIME_CALC 1

// Enable external speed control from moonshine controller, e.g. HelloDistiller
#define ENABLE_EXTERNAL_CONTROL 1

// Choose control signal 
#define EXT_CTRL_VIA_PWM		1   // PWM signal from pin 2(3)/interrupt 0(1), RPM = Duty*maxRpm.  Move encoder pins somewhere else.
#define EXT_CTRL_VIA_ANALOG		2   // analog 0-5V input from pins A6/A7, RPM = InputVoltage*maxRpm/5V
#define EXT_CTRL_VIA_PIN_PRESET 3   // set predefined RPM speed when corresponding pin is HIGH

#define EXTERNAL_CONTROL_TYPE   EXT_CTRL_VIA_PWM

// We can use simple moisture sensor to detect hose failure
#define ENABLE_MOISTURE_SENSOR   0

// Some sensors are inverted, i.e. has LOW output in wet environment and HIGH in  dry
// So we can account it with with option
#define MOISTURE_SENSOR_INVERTED 1

// Threshold above which pump will halt. Set threshold to 2-255 for analog input, or to 1 for digital input
// Note: A6 & A7 pins cannot do digitalRead() and should use analog input only, i.e. threshold>2
#define MOISTURE_SENSOR_THRESHOLD 300 


#define LCD_I2C_ADDRESS  0x3F // 0x27 // 0x3F 

#define ENCODER_STEP_PER_NOTCH 2

// Pump will display a warning after this number of liters pumped withour hose replacement
#define HOSE_WARNING_VOLUME 3000L 


// Hardware Settings
//================================================================================================
// pins numbers
const uint8_t pinEnable = A2;
const uint8_t pinStep = 10;
const uint8_t pinDir = A3;

const uint8_t pinMS1 = A1;
const uint8_t pinMS2 = A0;
const uint8_t pinMS3 = 13;

const uint8_t pinReset = 12;
const uint8_t pinSleep = 11;

#if ENABLE_MOISTURE_SENSOR
	const uint8_t pinMoistureSensor = A7;
#endif

#if ENABLE_EXTERNAL_CONTROL 
	#if EXTERNAL_CONTROL_TYPE == EXT_CTRL_VIA_PWM
		const uint8_t pinExtControl = 2;  // Interrupt 0
		// const uint8_t pinExtControl = 3;  // Interrupt 1
	#elif EXTERNAL_CONTROL_TYPE == EXT_CTRL_VIA_ANALOG
		const uint8_t pinExtControl = A7;  // Analog input pin
	#elif EXTERNAL_CONTROL_TYPE == EXT_CTRL_VIA_PIN_PRESET
		const uint8_t pinExtControl = 5;  // Starting digital pin for RPM preset selection, i.e. 6-8 for rpmPresetNum=3 

		// Presets are defined in RPM, i.e. revolutions per minute
		// If you want to set speed in ml/s or L/h you should convert it to mm/min and divide by revolution2millilitreCw constant
		// In the example below we set target speeds to {5 ml/min, 2 L/h, -150} RPM
		// Negative RPM values will result in CCW rotation direction
		extern float revolution2millilitreCw;  // forward declaration
		const uint8_t rpmPresetNum = 3;        // Number of predefined RPM speeds
		const double  rpmPresetValue[rpmPresetNum] = {5/revolution2millilitreCw, 2*1000/60/revolution2millilitreCw, -150};
	#endif
#endif // #if ENABLE_EXTERNAL_CONTROL

const uint8_t pinEncoderButton = 5;
const uint8_t pinEncoderA  = 6;
const uint8_t pinEncoderB  = 7;

// Speed & motor setup
const int8_t    microStepping = 8;
const int16_t   maxRpm = 450;			// Upper limit, won't increase RMP above this
const float     minRpm = 0.01;			// Lower limit, if RPM<minRpm, RPM will be set to 0
const int16_t   rpmAccelerationRate = 50;	// RPM increase per second when user change speed
const int16_t   rpmHaltRate = 200;		// RPM change per second when motor halts
const int16_t   calibrationRpm = 200;		// RPM for calibration

#if ENABLE_MODE_BOTTLING
int16_t		  bottlingRpm = 200;			// RPM for bottling
int16_t		  bottlingIncrementFactor = 10;	// When we need to pump large volume of liquid it will take too long 
											// to rotate the encoder to set the value. This factor allows to increase
											// the increment delta in bottling mode
#endif

const float   degreePerStep = 1.8;  // rather common value for widespread motors
const int16_t stepsPerRevolution = 360 / degreePerStep * microStepping;

// Variables
//================================================================================================

#define MODE_RPM			 0		// Control RPM
#define MODE_LITRES_PER_HOUR 1      // Control liquid volume per second
#define MODE_BOTTLING	 2      // Pump fixed volume of liquid
#define MODE_EXT_CONTROL 3	    // External control via PWM or analog signal

int8_t  pumpMode = 0;

#define LCD_WIDTH 16
#define LCD_HEIGHT 2

LiquidCrystal_I2C lcd(LCD_I2C_ADDRESS, LCD_WIDTH, LCD_HEIGHT);

int32_t  bottlingVolume = 500;
float    targetRpm = 0;
float    lastTargetRpm = 0;
float    currentRpm = 0;
int16_t  currentRpmRate = rpmAccelerationRate;

float revolution2millilitreCw = 2.6;	// This value is for 9*6 silicon hose
float revolution2millilitreCcw = 2.6;  // You should calibrate the pump by yourself

ClickEncoder *encoder;

volatile uint8_t speedAdjustmentTicks = 0;
volatile long stepCounter = 0;
volatile long bottlingStepLimit = 0;

// variable for uptime counting
uint32_t totalMotorUptime = 0;		// total motor uptime in seconds
double   totalHoseVolume = 0;		// total hose uptime in seconds, user may reset that by holding encoder button while powering on
double   totalPumpedVolume = 0;	    // total pumped volume in litres
float    lastCurrentRpm = 0;

#if ENABLE_MOISTURE_SENSOR
long lastSensorReadTime = 0;
bool haltOnHoseFailureFlag = 0;
#endif

#if ENABLE_UPTIME_CALC
const uint16_t volumeIntegralPeriodMs = 1000;
uint32_t eepromSaveTotalsPeriodMs = 60000;
uint32_t eepromRewriteCounter = 0;  // ATMEL gives 100000 cell rewrites lifetime
									// With eeprom update once in every minute we will hold for 100000/60/24 ~ 70 days
									// So for the first 10 minutes we will save uptime every minute
									//            after 10 minutes - every 5 minutes
									//            after 1 hour - every 10 minutes
#endif // ENABLE_UPTIME_CALC

#if ENABLE_EXTERNAL_CONTROL
	// User may want to halt the motor manually. We will use this flag to ignore external input.
	bool extControlDisabledFlag = true;
	uint32_t lastRpmSetTime = 0;
	volatile float extPwmDutyCycle = 0;
	volatile uint16_t extPwmPeriodNum = 0;    // PWM period counter to detect pulse presence
	const uint8_t  extCtrlAvgNum = 2;         // Number of PWM periods to average duty cycle, helps to prevent jitter
	const uint16_t extCtrlCheckPeriod = 3000; // Time interval to check for motor speed
	
	const float extCtrlPwmFactor = 0.45;      // Correction factor for external PWM duty cycle

											  // Note for HelloDistiller controller user:
	                                          // Â HelloDistiller ñëèøêîì ãðóáûé øàã - 1/125. À ñêîðîñòü íàñîñà ìàêñèìàëüíàÿ áîëüøàÿ ~65ë/÷
											  // Â ðåçóëüòàòå 1 øàã äàåò ñëèøêîì áîëüøîé ïðèðîñò ïîòîêà. ×òîáû óìåíüøèòü øàã ðåãóëèðîâêè
											  // ìû áóäåò óìåíüøàòü âíåøíèé PWM duty cycle. Ìàêñèìàëüíàÿ ñêîðîñòü ïðè ýòîìà ïðîëó÷èòüñÿ
											  // extCtrlPwmFactor*maxRpm
							
#endif

// Debug helpers
#if DEBUG_ENABLED
	#define DEBUG_BEGIN(baudRate)	Serial.begin(baudRate)
										// Prints debug message
	#define DEBUG_PRINT(...)		Serial.print(__VA_ARGS__)
	#define DEBUG_PRINTLN(...)		Serial.println(__VA_ARGS__)
										// Debug block may contain any code that we'll be switched off when debugging disabled
	#define DEBUG_BLOCK(block)		do { block; } while(0)	
#else
	#define DEBUG_BEGIN(...)
	#define DEBUG_PRINT(...)   
	#define DEBUG_PRINTLN(...) 
	#define DEBUG_BLOCK(block)
#endif

// EEPROM handling
//================================================================================================
template <typename T> int eepromGet(int addr, const T &t);
template <typename T> int eepromPut(int addr, const T &t);

// EEPROM helper function that return number of bytes writed/read
template <typename T> int eepromGet(int addr, const T &t ){
	EEPROM.get(addr, t);
	return(sizeof(t));
}
template <typename T> int eepromPut(int addr, const T &t ){
	EEPROM.put(addr, t);
	return(sizeof(t));
}

void eepromWrite() {
	uint32_t magic = MAGIC_BYTE; 
	int address = 0;
#if ENABLE_UPTIME_CALC
	eepromRewriteCounter++;
#endif  // !ENABLE_UPTIME_CALC

	address += eepromPut(address, magic);
	address += eepromPut(address, pumpMode);
	address += eepromPut(address, revolution2millilitreCw);
	address += eepromPut(address, revolution2millilitreCcw);
	address += eepromPut(address, lastTargetRpm);
	address += eepromPut(address, bottlingVolume);
#if ENABLE_MODE_BOTTLING
	address += eepromPut(address, bottlingIncrementFactor);
	address += eepromPut(address, bottlingRpm);
#endif
#if ENABLE_UPTIME_CALC
	address += eepromPut(address, totalMotorUptime);
	address += eepromPut(address, totalPumpedVolume);
	address += eepromPut(address, eepromRewriteCounter);
	address += eepromPut(address, totalHoseVolume);
#endif  // !ENABLE_UPTIME_CALC
}


bool eepromRead() {
	uint32_t magic; 
	int address = 0;

	address += eepromGet(address, magic);
	if (magic != MAGIC_BYTE) {
		eepromWrite(); // clear old data
		return false;
	}

	address += eepromGet(address, pumpMode);
	address += eepromGet(address, revolution2millilitreCw);
	address += eepromGet(address, revolution2millilitreCcw);
	address += eepromGet(address, lastTargetRpm);
	address += eepromGet(address, bottlingVolume);
#if ENABLE_MODE_BOTTLING
	address += eepromGet(address, bottlingIncrementFactor);
	address += eepromGet(address, bottlingRpm);
#endif
#if ENABLE_UPTIME_CALC
	address += eepromGet(address, totalMotorUptime);
	address += eepromGet(address, totalPumpedVolume);
	address += eepromGet(address, eepromRewriteCounter);
	address += eepromGet(address, totalHoseVolume);
#endif
	return true;
}

// Setup()
//================================================================================================
void setup() {
	DEBUG_BEGIN(115200);

	lcd.begin();
	lcd.clear();
	lcd.backlight();

	// Show invitation
	lcd.setCursor(0, 0);
	lcd.print(F("Peristaltic pump"));
	lcd.setCursor(0, 1);
	lcd.print(String(F("      v")) + String(firmwareVersion, 1) + String(F("      ")));

	encoder = new ClickEncoder(pinEncoderA, pinEncoderB, pinEncoderButton, ENCODER_STEP_PER_NOTCH);

	if (!eepromRead())
		DEBUG_PRINTLN(F("Failed to read EEPROM values"));

	// Setup pins
	pinMode(pinStep, OUTPUT);
	pinMode(pinDir, OUTPUT);
	pinMode(pinEnable, OUTPUT);
	pinMode(pinMS1, OUTPUT);
	pinMode(pinMS2, OUTPUT);
	pinMode(pinMS2, OUTPUT);
	pinMode(pinSleep, OUTPUT);
	pinMode(pinReset, OUTPUT);

#if	ENABLE_MOISTURE_SENSOR
	pinMode(pinMoistureSensor, INPUT);
#endif

#if ENABLE_EXTERNAL_CONTROL
	#if EXTERNAL_CONTROL_TYPE == EXT_CTRL_VIA_PIN_PRESET
		for (int pin = 0; pin < rpmPresetNum; pin++) pinMode(pinExtControl+pin, INPUT);
	#else
		pinMode(pinExtControl, INPUT);
	#endif
#endif

	// Stepper driver setup
	digitalWrite(pinEnable, HIGH);
	digitalWrite(pinReset, HIGH);
	digitalWrite(pinSleep, HIGH);

	// Choose microstepping
	switch (microStepping) {
	case 1:
		digitalWrite(pinMS1, LOW); 		digitalWrite(pinMS2, LOW); 		digitalWrite(pinMS3, LOW);
		break;
	case 2:
		digitalWrite(pinMS1, LOW); 		digitalWrite(pinMS2, HIGH); 	digitalWrite(pinMS3, LOW);
		break;
	case 4:
		digitalWrite(pinMS1, LOW);		digitalWrite(pinMS2, HIGH);		digitalWrite(pinMS3, LOW);
		break;
	case 8:
		digitalWrite(pinMS1, HIGH);		digitalWrite(pinMS2, HIGH);		digitalWrite(pinMS3, LOW);
		break;
	case 16:
		digitalWrite(pinMS1, HIGH);		digitalWrite(pinMS2, HIGH);		digitalWrite(pinMS3, HIGH);
		break;
	}


	cli();
	// set timer1 to driver the stepper motor
	TCCR1A = 0; // set TCCR1A register to 0
	TCCR1B = 0; // set TCCR1B register to 0
	TCNT1 = 0; // set counter value to 0

	TCCR1B |= _BV(WGM12);   // turn on CTC mode
	TCCR1A |= _BV(COM1B0);  // connect pin to interrupt
	// TIMSK1 |= _BV(OCIE1B); // enable timer compare interrupt

	// switch timer1 is  initially switched off by setting prescaler to 0
	// TCCR1B &= ~(_BV(CS12)| _BV(CS11) | _BV(CS10));

	// set timer2 interrupt at 1kHz
	TCCR2A = 0;  // set entire TCCR2A register to 0
	TCCR2B = 0;  // same for TCCR2B
	TCNT2 = 0;  // initialize counter value to 0

	// set compare match register for 1khz increments
	OCR2A = 249;  // (16 000 000) / (1000 * 64) - 1;

	TCCR2A |= _BV(WGM21);  // turn on CTC mode
	TCCR2B |= _BV(CS22);   // Set CS22 bit for 64 prescaler

	TIMSK2 |= _BV(OCIE2A); // enable timer compare interrupt

#if ENABLE_EXTERNAL_CONTROL && EXTERNAL_CONTROL_TYPE == EXT_CTRL_VIA_PWM
	// Attach interrupt handler
	attachInterrupt(digitalPinToInterrupt(pinExtControl), ExternalInputISR, CHANGE);
#endif

	sei();  // allow interrupts
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
void loop() {
	static long lastTime = 0;
	const uint32_t now = millis();
	const double rpm2ml = (targetRpm > 0) ? revolution2millilitreCw : revolution2millilitreCcw;

#if	ENABLE_MOISTURE_SENSOR
	if (!haltOnHoseFailureFlag && now - lastSensorReadTime > 777) {
		// Read the input on moisture sensor pin
		int sensorValue = (MOISTURE_SENSOR_THRESHOLD > 1) ? analogRead(pinMoistureSensor) : digitalRead(pinMoistureSensor);

		DEBUG_PRINT(F("Moisture sensor value is "));
		DEBUG_PRINTLN(sensorValue);

		#if MOISTURE_SENSOR_INVERTED
			if (sensorValue < MOISTURE_SENSOR_THRESHOLD) {
		#else
			if (sensorValue >= MOISTURE_SENSOR_THRESHOLD) {
		#endif
			lcd.clear();
			lcd.print("  Hose failure  ");
			lcd.setCursor(0, 1);
			lcd.print("    detected!   ");

			DEBUG_PRINTLN(F("WARNING! The hose failure was detected. The pump was halted!"));

			haltOnHoseFailureFlag = true;
		}
		lastSensorReadTime = now;
	}
	if (haltOnHoseFailureFlag) {
		currentRpmRate = rpmHaltRate;
		targetRpm = 0;
		adjustMotorSpeed();

		if (encoder->getButton() == ClickEncoder::Button_e::Clicked)
			haltOnHoseFailureFlag = false;
		return;
	}
#endif

#if ENABLE_UPTIME_CALC
	static long lastIntegralTime = 0;
	static long lastEepromSaveTime = 0;
	static long lastTotalMotorUptime = totalMotorUptime;
	static long eepromWriteCounter = 0;

	// Count pumped volume
	if (now - lastIntegralTime > volumeIntegralPeriodMs) {
		if (abs(currentRpm) > 0)
			totalMotorUptime += volumeIntegralPeriodMs / 1000;
		
		const double rpmIntegral = 0.5*(currentRpm + ((currentRpm*lastCurrentRpm > 0) ? 1 : -1)*lastCurrentRpm) / 60 * volumeIntegralPeriodMs / 1000;
		const double pumpedVolumeL = rpm2ml * abs(rpmIntegral) / 1000;

		totalPumpedVolume += pumpedVolumeL;
		totalHoseVolume += pumpedVolumeL;

		DEBUG_BLOCK({
			if (abs(rpmIntegral) > 0) {
				String line;
				uint32_t tmpMotorUptime = totalMotorUptime;
				if (totalMotorUptime >= 86400)		  line += String(int(totalMotorUptime / 86400)) + String(F("d "));
				if ((tmpMotorUptime %= 86400) > 3600)   line += String(int(tmpMotorUptime / 3600)) + String(F("h "));
				if ((tmpMotorUptime %= 3600) > 60)	  line += String(int(tmpMotorUptime / 60)) + String(F("m "));
				line += String(int(tmpMotorUptime % 60)) + String(F("s"));
				DEBUG_PRINT(F("Total motor uptime: "));
				DEBUG_PRINT(line);

				DEBUG_PRINT(F(". Total volume pumped: "));
				DEBUG_PRINT(totalPumpedVolume, 3);
				DEBUG_PRINTLN(F("L"));

			} });

		lastCurrentRpm = currentRpm;
		lastIntegralTime = now;
	}

	// Save totals to eeprom
	if (totalMotorUptime > lastTotalMotorUptime && now - lastEepromSaveTime > eepromSaveTotalsPeriodMs) {
		eepromWrite();
		lastTotalMotorUptime = totalMotorUptime;
		lastEepromSaveTime = now;
		// Increase eeprom save period to extend cell life
		if (++eepromWriteCounter > 10)		eepromSaveTotalsPeriodMs = 5 * 60 * 1000L; // 5 minutes
		else if (eepromWriteCounter > 20)	eepromSaveTotalsPeriodMs = 10 * 60 * 1000L; // 10 minutes
	}
#endif  // ENABLE_UPTIME_CALC

#if ENABLE_EXTERNAL_CONTROL
		if (pumpMode == MODE_EXT_CONTROL && now - lastRpmSetTime > extCtrlCheckPeriod) {  // check duty cycle once per extCtrlCheckPeriod 
			if (extControlDisabledFlag) {
				targetRpm = 0;
			} else {
			#if EXTERNAL_CONTROL_TYPE == EXT_CTRL_VIA_PWM
				if (extPwmPeriodNum < 1)  // no pulse on input pin means either 0% or 100%
					extPwmDutyCycle = digitalRead(pinExtControl);
				DEBUG_PRINT(F("PWM frequency: "));		DEBUG_PRINT(extPwmPeriodNum);		DEBUG_PRINTLN(F(" Hz"));
				DEBUG_PRINT(F("PWM duty cycle: "));		DEBUG_PRINT(extPwmDutyCycle * 100, 2);		DEBUG_PRINTLN(F("%"));
				targetRpm = maxRpm * extPwmDutyCycle;
				extPwmPeriodNum = 0;
			#elif EXTERNAL_CONTROL_TYPE == EXT_CTRL_VIA_ANALOG
				targetRpm = 1.0*maxRpm*analogRead(pinExtControl) / 255;
			#elif EXTERNAL_CONTROL_TYPE == EXT_CTRL_VIA_PIN_PRESET
				targetRpm = 0;
				currentRpmRate = rpmHaltRate;
				for (int pin = 0; pin < rpmPresetNum; pin++) {
					if (digitalRead(pinExtControl+pin) == HIGH) {
						targetRpm = rpmPresetValue[pin];
						currentRpmRate = rpmAccelerationRate;
						break;
					} // if (digitalRead(pin) == HIGH)
				} // for(;;)
			#endif
			}		

			if (targetRpm > maxRpm) targetRpm = maxRpm;
			if (targetRpm < -maxRpm) targetRpm = -maxRpm;
			if (abs(targetRpm) < minRpm) targetRpm = 0;

			lastRpmSetTime = now;
		}
#endif // #if ENABLE_EXTERNAL_CONTROL

	// process encoder rotation
	float delta = encoder->getValue();
	if (delta) {
		currentRpmRate = rpmAccelerationRate;

		switch (pumpMode) {
		case MODE_RPM:
			targetRpm += delta;
			targetRpm = round(targetRpm);
			break;
		case MODE_LITRES_PER_HOUR:
			if (DISPLAY_LITRES_PER_HOUR) {
				const double clph = round(targetRpm*rpm2ml*0.6) + delta;
				targetRpm = clph / rpm2ml / 0.6;
			} else {
				const double cmlpm = round(targetRpm*rpm2ml) + delta;
				targetRpm = cmlpm / rpm2ml;
			}
			break;
		#if ENABLE_MODE_BOTTLING
		case MODE_BOTTLING:
			// don't change volume if pumping right now
			if (bottlingStepLimit < 1) {
				bottlingVolume += delta*bottlingIncrementFactor;
				eepromWrite();
			}
			break;
		#endif
		#if ENABLE_EXTERNAL_CONTROL
		case MODE_EXT_CONTROL:
			break;
		#endif
		default:
			break; // no actions here
		} // switch (pumpMode) 

		if (targetRpm > maxRpm) targetRpm = maxRpm;
		if (targetRpm < -maxRpm) targetRpm = -maxRpm;
		if (abs(targetRpm) < minRpm) targetRpm = 0;

		displayPumpData();
	} // if (delta) 

	// process encoder buttons
	switch (encoder->getButton()) {
	case ClickEncoder::DoubleClicked:
		switch (pumpMode) {
		case MODE_RPM:
		case MODE_LITRES_PER_HOUR:
			if (abs(targetRpm) > 1e-2) {
				currentRpmRate = rpmHaltRate;
				lastTargetRpm = targetRpm;
				targetRpm = 0;
				eepromWrite();
			} else {
				currentRpmRate = rpmAccelerationRate;
				targetRpm = lastTargetRpm;
			}
			break;
		#if ENABLE_MODE_BOTTLING
		case MODE_BOTTLING:
			if (bottlingStepLimit > 0) {
				bottlingStepLimit = 0;
			} else {
				currentRpmRate = rpmAccelerationRate;
				stepCounter = 0;
				bottlingStepLimit = (long)abs(2.0*bottlingVolume / ((bottlingVolume > 0) ? revolution2millilitreCw : revolution2millilitreCcw) * stepsPerRevolution);
				TIMSK1 |= _BV(OCIE1B);  // enable timer compare interrupt
				targetRpm = (bottlingVolume > 0) ? bottlingRpm : -bottlingRpm;
			}
			break;
		#endif
		#if ENABLE_EXTERNAL_CONTROL	
		case MODE_EXT_CONTROL:
			extControlDisabledFlag = !extControlDisabledFlag;
			if (extControlDisabledFlag) {
				currentRpmRate = rpmHaltRate;
				targetRpm = 0;
			} else {
				currentRpmRate = rpmAccelerationRate;
			}
			break;
		#endif // ENABLE_EXTERNAL_CONTROL
		default:
			break; // no actions here
		} // switch (pumpMode) 
		break;
	case ClickEncoder::Clicked:
		encoder->setAccelerationEnabled(true);
		switch (pumpMode) {
		case MODE_RPM:
			pumpMode++;
			{
				float factor = (currentRpm > 0) ? revolution2millilitreCw : revolution2millilitreCcw;
				currentRpm = round(currentRpm * factor) / factor;
			}
			break;
		case MODE_LITRES_PER_HOUR:
		#if ENABLE_MODE_BOTTLING 
			pumpMode = MODE_BOTTLING;
			// halt pump
			currentRpmRate = rpmHaltRate;
			targetRpm = 0;
		#elif ENABLE_EXTERNAL_CONTROL		
			pumpMode = MODE_EXT_CONTROL;
			// halt pump
			currentRpmRate = rpmHaltRate;
			targetRpm = 0;
		#else
			pumpMode = MODE_RPM;
		#endif // MODE_BOTTLING			
			break;
		#if ENABLE_MODE_BOTTLING
		case MODE_BOTTLING:
			if (bottlingStepLimit < 1) // dont switch if pumping right now
			#if ENABLE_EXTERNAL_CONTROL
				pumpMode = MODE_EXT_CONTROL;
		#else
				pumpMode = MODE_RPM;
		#endif
			break;
		#endif
		#if ENABLE_EXTERNAL_CONTROL
		case MODE_EXT_CONTROL:
			pumpMode = MODE_RPM;
			// halt pump
			currentRpmRate = rpmHaltRate;
			targetRpm = 0;
			extControlDisabledFlag = 1;  // user should confirm pump start every time in ext mode
			break;
		#endif // ENABLE_EXTERNAL_CONTROL

		default:
			pumpMode = MODE_RPM;
			break; // no actions here
		}
		eepromWrite();
		displayPumpData();
		break;
	case ClickEncoder::Held:
		// don't start calibration if pumping right now or in external control mode 
	#if ENABLE_MODE_BOTTLING
		if (pumpMode == MODE_BOTTLING) {
			if(bottlingStepLimit < 1) 	bottlingMenu();
			// Wait button release
			while (encoder->getButton() == ClickEncoder::Held)
				; // do nothing
			break;
		}
	#endif
	#if ENABLE_EXTERNAL_CONTROL
		if (pumpMode == MODE_EXT_CONTROL)
			break;
	#endif // ENABLE_EXTERNAL_CONTROL

		if (calibratePump()) {
			lcd.setCursor(0, 0);
			lcd.print(F("Pump calibration"));
			lcd.setCursor(0, 1);
			lcd.print(F("is finished     "));

			eepromWrite();
		} else {
			lcd.setCursor(0, 0);
			lcd.print(F("Pump calibration"));
			lcd.setCursor(0, 1);
			lcd.print(F("was canceled    "));
		}
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

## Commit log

2018-10-11 Initial version & schematics
2018-10-11 Updates schematics and added Fritzing source
    Added Fritzing source file and parts files for stepper driver, lcd & dc-dc converter
    [peristaltic-pump.fzz]
2018-10-12 Add OpenSCAD source code & assembly image
    Latest SCAD & STL files are still available at www.thingiverse.com/thing:3148717
    [605zz.scad, Hose_adapter.scad, pump.scad]
2018-11-27 Rename Peristaltic Pump.ino to PeristalticPump.ino
2018-11-27 Update to v1.1
    * Added external libraries
    * Added DISPLAY_LITRES_PER_HOUR to switch between ml/m to l/hr units
    * Fix pinSleep number
    * Added DISABLE_MODE_MILLILITRE macro to disable "Pumping predefined amount of liquid" mode
2018-11-27 Update SCAD files
    * Added pump case model
    * Modify hose adapters
    * Added naca_sweep external deps
    [605zz.scad, Hose_adapter.scad, Naca4.scad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]
2018-11-27 Added assembly image with case
2019-03-04 Cleanup old folder structure
    [605zz.scad, Hose_adapter.scad, Naca4.scad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]
2019-03-04 * Update pump case to v5
    [5 pin header.stp, 605zz.scad, 90d pin_header.stp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]
2019-03-04 * New hose fixing cover, no hose insets any more * Added spring guide for 0.7*7*15 springs * Increase rotor axes clearance * Modify encoder mount * Increase hole for screws in LCD and back cover moun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
    [BoardOutline.gbr, Bottom.gbr, BottomAssy.gbr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]
2019-03-04 * Fix file naming * Remove older versions
    [case-bottom.stl, case-v3-bottom.stl, case-v3-top.stl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]
2019-03-04 * Added firmware source file * Added Fritzing sources & schematics
    [case.scad, encoder-knob.stl, head-assembly.stl]
2019-03-04 * Added moisture sensor to detect hose failure * Added uptime & total volume pumped counters
    [firmware.ino]
2019-03-04 * Added external control of pump speed via PWM or analog signal
2019-03-04 Fix VCC/GND pins silk
2019-03-04 Added LCD macros & pin encoder pin definition depending on EXTERNAL_CONTROL_TYPE
2019-03-04 * Add Arduino IDE libraries for I2C LCD & click encoder * Remove backup folder
    [5 pin header.stp, 90d pin_header.stp, Naca4.scad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]
2019-03-04 Added docs & compiled stl files for 9*6 silicon hose
    [case-bottom.stl, case-with-support.stl, case.stl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]
2019-03-05 * Update encoder pinout in schematics
2019-03-05 * Update schematics JPG
2019-03-09 * Added new external control mode, i.e. predefined RPM selection via setting corresponding digital pin to HIGH state * Adjusted default calibration factor for 9*6 silicon hose (revolution2millilitre)
2019-03-11 * Added hose life calculation & hose replacement warning * Added settings for moisture sensor with inverted output
    [firmware.ino]
2019-03-13 * Added encoder knob to case assembly
    [case.scad]
2019-03-16 * Added mount for moisture sensor on bottom cover * Added supports at case angle to prevent head plane curving when printing
    [case-bottom.stl, case.scad, case.stl]
2019-03-19 Reduce size of motor plane support for pump case
    [case.scad, case.stl]
2019-03-19 * Add PWM & analog input circuits to schematics
2019-03-28 * Added angle skirt for ABS printing
    [pump-stator-base-with-support.stl, pump-stator-cover-with-support.stl, pump-stator-support-with-support.stl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]
2019-03-28 * Added external PWM board
2019-03-29 * Added passive components value on schematics
2019-03-30 * Disable moisture sensor by default
2019-03-30 * Fix external control for very long PWM period (frequency <1Hz). Checked with HelloDistiller moonshine controller
    [firmware.ino]
2019-04-02 * Add scaling factor for external PWM
2019-04-12 * Fix integer oveflow warning
    [firmware.ino]
2019-04-13 * Fix bottling volume max value. Change type from int to long to allow value > 32L * Improve bottling volume display for large volumes
    [firmware.ino]
2019-04-14 * Move encoder pins to D5-D7 both in schematics & sketch
2019-10-10 Update README.md
    Provide links to sample items on Aliexpress
2019-12-16 Update firmware.ino
    Fix compilation error for ENABLE_UPTIME_CALC = 0
    [firmware.ino]
2020-03-31 Fix springs url in readme
2020-04-23 Update schematics to the latest version
2020-10-16 Update PCBs to the latest version for both black & blue arduino pro mini. All PCBs are single sided and can be "ironed" or routed at home.
    [peristaltic-pump.fzz]

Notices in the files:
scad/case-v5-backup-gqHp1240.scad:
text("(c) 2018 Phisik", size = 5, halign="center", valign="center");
